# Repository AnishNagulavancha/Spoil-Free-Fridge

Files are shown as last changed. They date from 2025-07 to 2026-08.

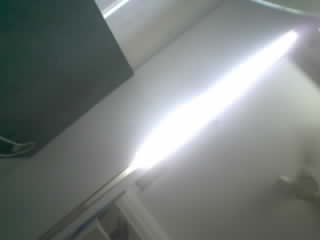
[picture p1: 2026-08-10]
firmware/main/capture_test_output/capture_test_2_20260808_180124.jpg

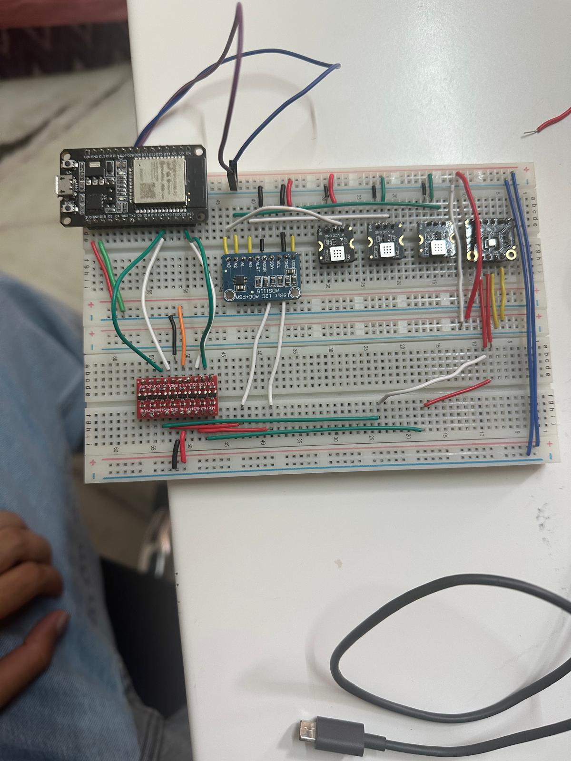
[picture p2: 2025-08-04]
Visuals and Designs/BreadBoard Prototype build.jpeg

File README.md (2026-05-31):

# Spoil-Free-Fridge
This project is a battery-powered, IOT system designed to detect early signs of food spoilage in refrigerators by monitoring the release of specific gases and image classification. It uses dedicated gas sensors (specifically, hydrogen sulfide, ammonia, and methane) along with an environmental sensor (BME688) and and ESP32-S3 Sense to track changes in air composition over time.

The collected data is transmitted to a PC over Wi-Fi using an ESP32-S3 microcontroller. A machine learning model, trained on labeled gas profiles of different food states, will follow a multi-classification approach by being able to recongize food type, food item, and finally the freshness level as fresh, spoiling, or spoiled. Another model will use a public dataset of images of fresh vs rotten for visual detection.

The system is optimized for low power consumption, designed to operate off a LiPo, and intended for eventual deployment inside consumer refrigerators as a compact, standalone freshness detection unit.

Currently, a custom PCB is being designed and a 3D CAD model will be designed for the outer casing of the PCB. Initially, we will see if the prototype is accurate enough to work in normal conditions before moving to a fridge

The inspiration of this project came out my own laziness of postponing when I would cook my own meals leading to food spoiling in the fridge.

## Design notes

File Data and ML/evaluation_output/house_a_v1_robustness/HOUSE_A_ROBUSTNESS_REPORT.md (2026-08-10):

# House A robustness analysis

## Status

HouseA_v1 remains the primary frozen result. All analyses below are robustness
checks or retrospective exploratory analyses; none changes the frozen result.

## Frozen benchmark

- Confirmations detected: 3/3
- Calibration-control events under the full calibration: 0/3
- Confirmation detection range: 1.75–3.75 h
- Confirmation AUC range: 206.48–313.48
- Calibration-control AUC range: 0.47–10.92

The controls above participated in calibration; their zero-event count is a
calibration diagnostic, not an independent false-positive estimate.

## Full leave-one-control-out result

- Held-out controls with events: 1/3
- Confirmation detections across folds: 3–3 of 3
- Minimum fold-level absolute AUC margin: 118.83
- Detection times across calibrations: 1.25–4.25 h

## Parameter sensitivity

- 23/23 configurations retained all three confirmation events.
- 0/23 produced zero leave-one-control-out control events.
- 23/23 retained a positive minimum-chicken minus maximum-control AUC margin.
- 0/23 (0.0%) met all three criteria simultaneously.

These are grid-robustness proportions, not probabilities that the detector is
biologically correct.

## Ablation

- Event rules retaining 3/3 confirmations and 0/3 controls: h2s_and_bme
- Index variants with positive minimum-confirmation minus maximum-control AUC margin: 6/6

## Control bootstrap stress test

For the eight-hour window, conditional moving-block bootstrap false-session
rates ranged from 0.00% to
16.35% across 15–90 minute blocks. The
intervals in the CSV quantify Monte Carlo error only; three observed controls
cannot characterize between-session or between-house uncertainty.

One of 12 shifted-baseline control stress tests produced an event.
It was house_A_pcb_A_S005_Anish_control_empty_20260724_125849
with a 120-minute shift. This shows that the cumulative event can be
sensitive to baseline placement even when the displayed index remains small.

## Environmental sensitivity

Environment-adjusted detection pairs (original → adjusted, hours):
3.75 → 5.92; 1.75 → 5.50; 2.00 → 8.75.

Every environmental result is exploratory because the chicken sessions extend
beyond the control humidity/temperature training domain. A changed detection
time demonstrates sensitivity to the adjustment; it does not identify a true
biological onset.

The prespecified delta-RH plus delta-temperature model had mean held-out RMSE
0.0800, versus 0.0705 for the simple time-only regression.
It therefore did not improve aggregate control generalization and should not
replace the frozen correction.

## Alternative transition estimates

The detailed table distinguishes online CUSUM onset, a control-calibrated rapid
rise, Page–Hinkley onset, and an offline whole-trajectory mean shift. Agreement
indicates a stable statistical transition, not microbiological validation.
The offline mean-shift locations were
4.75 h, 4.75 h, 6.67 h;
their absolute shift magnitudes exceeded every leave-one-control-out control,
although their normalized SSE gains did not. Page–Hinkley onsets were
4.92 h, 4.67 h, 6.33 h.

## Session-level inference

- Perfect descriptive AUC ordering: True
- LOO-control AUC range: 0.31–54.18
- Confirmation AUC range: 206.48–313.48
- Pairwise Hodges–Lehmann location difference: 238.20 index-hours

No formal permutation p-value is reported because the available controls define
the calibration and are not untouched exchangeable validation sessions.

## Quality flags

The quality flags are deterministic diagnostics, not calibrated probabilities.
Flag counts across confirmations: 3, 3, 3.

## Conclusion

The magnitude separation is robust: every parameter and index ablation retained
a positive chicken-versus-control AUC margin. The exact Boolean event and its
onset are less robust because one cross-fitted control fires and onset varies
with calibration and transition method. The appropriate claim remains that
chicken exposure produced a repeatable, sustained, control-adjusted multichannel
headspace response in the House A apparatus. These analyses cannot establish
microbial spoilage, food safety, remaining useful life, or universal household
performance.

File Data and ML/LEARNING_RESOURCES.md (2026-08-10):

# Learning guide for the control-calibrated prototype

This guide explains what the active files do, the theory behind them, and a
practical order for learning the implementation. The pipeline estimates
**deterioration-associated sensor and image change**. It does not measure food
safety or microbiological spoilage unless it is validated against laboratory
ground truth.

## 1. Read the project in this order

1. `Datalog_pcb.py` — serial acquisition, warmup/prompt phases, metadata,
   images, and session roles.
2. `analyze_session.py` — parsing, cleaning, timestamp indexing, one-minute
   aggregation, baselines, deltas, rolling slopes, volatility, and biological
   age.
3. `configs/house_a_v1.json`, `configs/house_a_v2_candidate.json`, and
   `experiment_config.py` — versioned frozen choices and validation.
4. `model_data.py` — loading and resampling complete sessions without treating
   adjacent rows as independent experiments.
5. `unsupervised_models.py` — control drift correction, leave-one-control-out
   scale estimation, CUSUM calibration, PCA, Isolation Forest, and the change
   index.
6. `run_models.py` — command-line orchestration and safeguards separating
   controls, pilot data, and confirmation data.
7. `aggregate_site_results.py` — session-level cross-house summaries without
   pooling autocorrelated raw sensor rows.
8. `image_data.py` and `image_features.py` — image timestamps, ROIs, color,
   histogram, texture, edge, blur, and baseline-relative features.
9. `camera_models.py` and `run_camera_models.py` — camera baseline model,
   condensation gate, anomaly persistence, and reliability by hour.

Before reading the project, work through the
[Python tutorial](https://docs.python.org/3/tutorial/index.html),
[NumPy quickstart](https://numpy.org/doc/stable/user/quickstart.html), and
[pandas time-series guide](https://pandas.pydata.org/docs/user_guide/timeseries.html).
The [pySerial introduction](https://pyserial.readthedocs.io/en/stable/shortintro.html)
matches the serial-port concepts used by the logger.

## 2. Cleaning, resampling, and feature engineering

The raw samples are autocorrelated and much faster than the biological changes
of interest. Median aggregation reduces isolated spikes without pretending that
every two-second sample is an independent experiment. Learn pandas
[`resample`](https://pandas.pydata.org/docs/user_guide/timeseries.html#resampling)
and [`rolling`](https://pandas.pydata.org/pandas-docs/stable/reference/api/pandas.DataFrame.rolling.html),
then review NIST's
[least-squares regression](https://www.itl.nist.gov/div898/handbook/pmd/section1/pmd141.htm).
The rolling slope is simply the fitted coefficient of time over a moving
window; acceleration is a slope of those slopes.

The biological-age feature uses the explicit engineering assumption

```text
Q10 factor = 2 ** ((temperature_C - 4) / 10)
biological hours += Q10 factor * elapsed_clock_hours
```

Q10 describes how a deterioration rate changes for a 10 degrees C temperature
change. It is a model assumption, not a sensor measurement and not proof of
shelf life. A useful food-cold-chain introduction is the
[FAO discussion of Q10](https://openknowledge.fao.org/3/i8017en/I8017EN.pdf).

Practice:

1. Create a noisy synthetic signal with a few spikes and compare one-minute
   means with medians.
2. Implement a rolling five-point slope by hand, then compare it with the
   project output.
3. Calculate biological age for constant 4, 14, and 24 degrees C data and
   explain why the factors are 1, 2, and 4.

## 3. Controls, robust scale, and drift correction

An empty control measures environmental and instrument behavior when chicken is
absent. The code pools controls to estimate smooth expected drift. It then uses
leave-one-control-out residuals: fit the correction without one control, apply
it to that held-out control, and measure the remaining null variation. This
tests the complete correction process instead of only the baseline noise.

The residual scale uses median absolute deviation (MAD), a robust alternative
to standard deviation. Read the
[SciPy MAD definition](https://docs.scipy.org/doc/scipy/reference/generated/scipy.stats.median_abs_deviation.html)
and NIST's
[LOESS overview](https://www.itl.nist.gov/div898/handbook/pmd/section1/pmd144.htm)
for the reasoning behind robust scale and smooth drift estimation. The project
uses its own deterministic smoothing implementation, so focus on the ideas
rather than expecting identical library calls.

The block bootstrap resamples consecutive blocks instead of individual rows so
short-range time dependence is retained. The original reference is Kunsch,
[The Jackknife and the Bootstrap for General Stationary Observations](https://doi.org/10.1214/aos/1176347265).

Practice:

1. Implement `MAD = 1.4826 * median(abs(x - median(x)))` and test it after
   adding one extreme outlier.
2. Hold out each of three synthetic controls, fit drift on the other two, and
   plot the held-out residuals.
3. Compare an ordinary row bootstrap with a block bootstrap on a slowly varying
   signal.

## 4. CUSUM and the primary event rule

CUSUM accumulates small deviations that persist in one direction. For a
standardized response `z`, the one-sided update is conceptually

```text
C_t = max(0, C_(t-1) + z_t - k)
signal when C_t > h
```

`k` ignores small movement and `h` controls how much accumulated evidence is
required. Study NIST's
[CUSUM control-chart explanation](https://www.itl.nist.gov/div898/handbook/pmc/section3/pmc323.htm)
and [average run length](https://www.itl.nist.gov/div898/handbook/pmc/section3/pmc3131.htm).
This project calibrates CUSUM behavior using empty controls and freezes the rule
before prospective scoring. HouseA_v1 uses `(NH3 or H2S) AND BME688`.
HouseA_v2 uses `H2S AND BME688`, selected from the excluded pilot and
cross-fitted controls. CH4 remains supporting evidence. This is evidence
agreement, not proof that the channels are independent.

Practice: implement the recurrence above in ten lines, feed it zero-mean noise,
then add a small sustained shift. Compare how detection changes for different
`k` and `h` values.

## 5. PCA, Isolation Forest, and the change index

PCA rotates correlated standardized channels into orthogonal directions that
capture decreasing amounts of variance. It is a visualization and compression
tool, not a spoilage detector. Read the scikit-learn
[PCA documentation](https://scikit-learn.org/stable/modules/generated/sklearn.decomposition.PCA.html).
Always inspect component loadings and compare control and chicken trajectories;
otherwise PC1 may simply describe drift or elapsed time.

Isolation Forest isolates unusual observations through random feature splits;
points requiring fewer splits are more anomalous. Start with the
[original paper](https://doi.org/10.1109/ICDM.2008.17), then read the
[scikit-learn implementation](https://scikit-learn.org/stable/modules/generated/sklearn.ensemble.IsolationForest.html).
The model is fitted to corrected control-null data, so its question is
"unusual relative to empty controls?" rather than "spoiled?".

The 0-100 change index is a transparent engineered metric: each directed,
control-corrected z-score is clipped to 0-1 using the frozen `full_scale_z`,
then the channels are combined with the weight set in the selected versioned
configuration. Those weights are a documented protein-food
heuristic, not learned coefficients. They affect the index but not the primary
CUSUM agreement event. AUC is integrated only over the fixed 0-8 hour window
and is invalidated when coverage rules fail. This keeps it comparable across
complete sessions, but the index remains a prototype effect-size scale rather
than a probability or percentage spoiled.

Practice:

1. Fit PCA to two correlated synthetic sensors and reproduce the transformed
   coordinates from the component matrix.
2. Fit Isolation Forest to a cloud of normal points plus five distant points;
   inspect scores rather than only binary labels.
3. Recalculate one row of the project change index by hand from its four
   corrected z-scores and the JSON weights.

## 6. Camera theory

The camera pipeline uses fixed regions of interest and interpretable features,
not a CNN. With only a few sessions, a CNN would mostly learn lighting,
container position, and condensation. Begin with the
[Pillow tutorial](https://pillow.readthedocs.io/en/stable/handbook/tutorial.html)
for loading, cropping, and transforming images. For edges and the blur gate,
read OpenCV's explanation of
[image gradients and the Laplacian](https://docs.opencv.org/master/d5/d0f/tutorial_py_gradients.html).

Laplacian variance falls when sharp edges disappear. The code requires both the
chicken ROI and a stationary background ROI to become blurry before treating a
frame as likely fogged. Rejected frames cannot build a persistent anomaly, and
reliability is reported over time so late-session condensation is visible.

Practice:

1. Crop the same ROI from a sharp image and a blurred copy; calculate
   Laplacian variance for both.
2. Change image brightness without changing the object and observe which color
   and histogram features move.
3. Cover only the chicken ROI, then blur the whole image, and verify why the
   background ROI distinguishes occlusion/change from global fogging.

## 7. Experimental validity and ground truth

The most important modeling rule is to keep confirmation sessions and sites
untouched while choosing directions, thresholds, weights, and scales. Read scikit-learn's
[data-leakage guidance](https://scikit-learn.org/stable/common_pitfalls.html#data-leakage)
and the OSF
[registration guide](https://help.osf.io/article/330-welcome-to-registrations)
to understand why the pilot is excluded and the configuration is frozen.

The exact sensor directions and limitations must come from the manufacturers'
datasheets and independent response checks. For the BME688, use Bosch's
[product documentation and datasheet](https://www.bosch-sensortec.com/en/products/environmental-sensors/gas-sensors/bme688/).
Do not improvise concentrated toxic-gas sources.

Visible observations are useful supporting annotations, but defensible
spoilage ground truth needs independent measurements. The FDA's
[Bacteriological Analytical Manual](https://www.fda.gov/food/laboratory-methods-food/bacteriological-analytical-manual-bam)
and [Aerobic Plate Count chapter](https://www.fda.gov/food/laboratory-methods-food/bam-chapter-3-aerobic-plate-count)
show what a microbiological reference method looks like. Until those data
exist, report detection latency, control-adjusted index, fixed-window AUC,
sensor agreement, camera reliability, and repeatability across independent
sessions—not accuracy, sensitivity, specificity, freshness probability, or
remaining shelf life.

## 8. Cross-house generalization

The portable design separates local calibration from global logic. Each
site/device/container estimates its own baseline, drift, and residual noise;
the sensor directions, CUSUM rule, persistence, index weights, and scale remain
globally frozen. Never average raw voltages across houses. Compare standardized
session-level metrics instead.

If two houses influence model choices, both are development sites. Test the
frozen procedure at an untouched third house to evaluate external transfer.
Later, use leave-one-house-out validation: develop on every site except one and
evaluate the complete calibration-and-detection procedure at the held-out site.

## 9. Accelerated two-week study plan

- Days 1–2: Python, NumPy, pandas, and serial logging; trace one row from serial
  input to `sensor_log.csv`.
- Days 3–4: resampling, baselines, deltas, rolling statistics, MAD, and Q10;
  reproduce one feature column in a scratch script.
- Days 5–6: implement CUSUM from scratch and understand the primary agreement
  rule.
- Days 7–8: PCA and Isolation Forest on synthetic data, then empty controls.
- Days 9–10: image ROIs, color features, Laplacian variance, condensation, and
  anomaly persistence.
- Days 11–12: run a short practice session through every command and inspect
  each output.
- Days 13–14: explain the design, assumptions, failure modes, and claims
  without relying on the code.

This is roughly 25–35 focused hours. You are not expected to reproduce every
file from memory; you should be able to explain the major decisions, follow one
reading through the pipeline, run it, interpret it, and make small documented
changes.

For every algorithm, use the same loop: derive the smallest formula, implement
it on synthetic data, plot failure cases, then read the corresponding project
function. That will teach you more than trying to understand the entire
pipeline in one pass.

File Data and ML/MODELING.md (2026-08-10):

# Sensor and camera modeling workflow

This prototype detects control-adjusted headspace change. It does not measure
microbial counts, determine food safety, report a percentage spoiled, or provide
a validated remaining-useful-life estimate.

## Active analysis versions

- `configs/house_a_v1.json` reproduces the completed House A analysis. Its
  primary event is `(NH3 OR H2S) AND BME`.
- `configs/house_a_v2_candidate.json` is frozen for the next prospective test.
  Its primary event is `H2S AND BME`, selected from the excluded pilot and
  cross-fitted controls. It is not yet prospectively validated.

The acquisition metadata retains the historical protocol identifier
`prototype_1_control_calibrated_4h_v2` for compatibility. The active analysis
window is eight hours.

## Acquisition and feature generation

`Datalog_pcb.py` records sensors, images, metadata, a 30-minute empty-chamber
warmup, and the post-prompt session. A prospective session used for the frozen
analysis must contain at least eight post-prompt hours.

After acquisition, create the one-minute features:

```powershell
python analyze_session.py "C:\path\to\session"
```

The default is the v2 candidate configuration. Use `--config` explicitly when
reproducing v1.

## Local control calibration

Each site/device/container requires its own controls. Do not pool raw voltages
across houses.

```powershell
python run_models.py `
  --controls "C:\data\C1" "C:\data\C2" "C:\data\C3" `
  --config configs\house_a_v2_candidate.json `
  --output-dir "house_A_v2_model"
```

Calibration estimates smoothed drift, leave-one-control-out MAD scales, the
control-null CUSUM behavior, PCA, Isolation Forest, and the environmental range
represented by the controls.

## Prospective scoring

Do not change the v2 candidate before scoring the next untouched session:

```powershell
python run_models.py `
  --calibration "evaluation_output\house_a_v2_candidate\control_calibration_candidate.joblib" `
  --targets "C:\data\new_session" `
  --config configs\house_a_v2_candidate.json `
  --output-dir "prospective_v2_result"
```

Interpret the outputs as follows:

- The 0–100 Change Index is an engineered response magnitude, not a spoilage
  percentage.
- The Boolean event is sustained multichannel departure from the control model,
  not the moment food becomes unsafe.
- `environment_domain_warning=true` means the session left the temperature or
  humidity range represented by the controls; the event remains visible but
  requires caution.
- AUC is always evaluated over the fixed 0–8-hour window.

## Reproduction and robustness

Rebuild the completed v1 robustness outputs with:

```powershell
python house_a_robustness.py
```

Rebuild the frozen v2 candidate selection and diagnostics with:

```powershell
python run_house_a_v2_candidate.py
```

Canonical generated results are kept in:

- `evaluation_output/full_stack_4runs_20260806` — processed House A sessions
  and the original v1 calibration;
- `evaluation_output/house_a_v1_robustness` — v1 robustness findings;
- `evaluation_output/house_a_v2_candidate` — frozen v2 candidate artifact and
  retrospective diagnostics.

## Camera analysis

Camera analysis is optional and separate from the present sensor conclusion:

```powershell
python run_camera_models.py "C:\path\to\session" `
  --roi .1,.2,.9,.9 `
  --background-roi 0,0,1,.15
```

Fogged or unreliable frames are flagged and cannot establish food safety.

## Cross-site results

Score every site with its own local calibration but the same frozen global
configuration. Combine only confirmation-level summaries:

```powershell
python aggregate_site_results.py `
  "house_A_result\sensor_summary.json" `
  "house_B_result\sensor_summary.json" `
  --output cross_site_summary.json
```

Generalization requires prospective sessions from additional devices, houses,
environmental ranges, and ultimately independent biological ground truth.

## Installation and tests

```powershell
python -m pip install -r requirements.txt
python -m pytest -q
```

See `LEARNING_RESOURCES.md` for theory and implementation references.

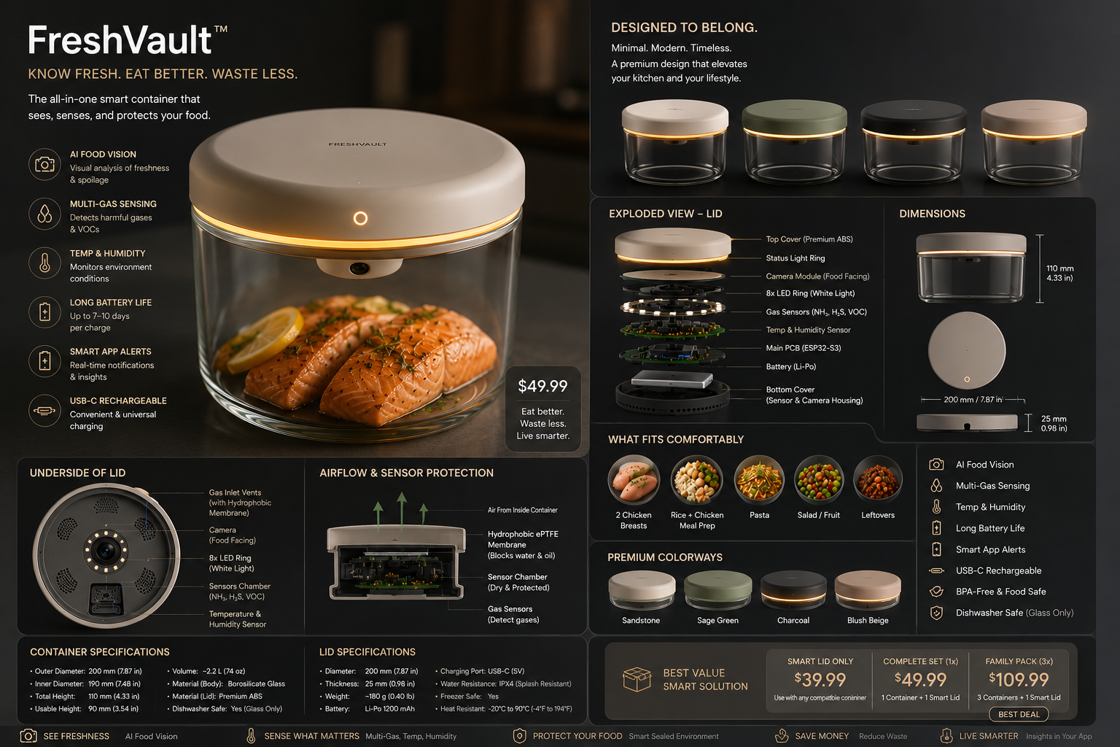
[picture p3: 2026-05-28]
Visuals and Designs/Prototype Visual #1.png

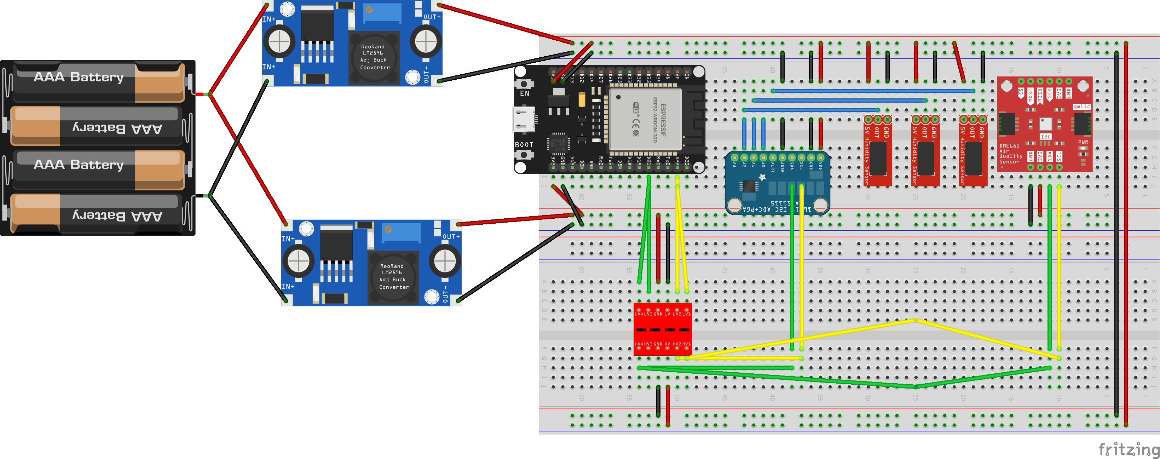
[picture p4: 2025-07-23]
Visuals and Designs/Fritzing prototype design.jpg

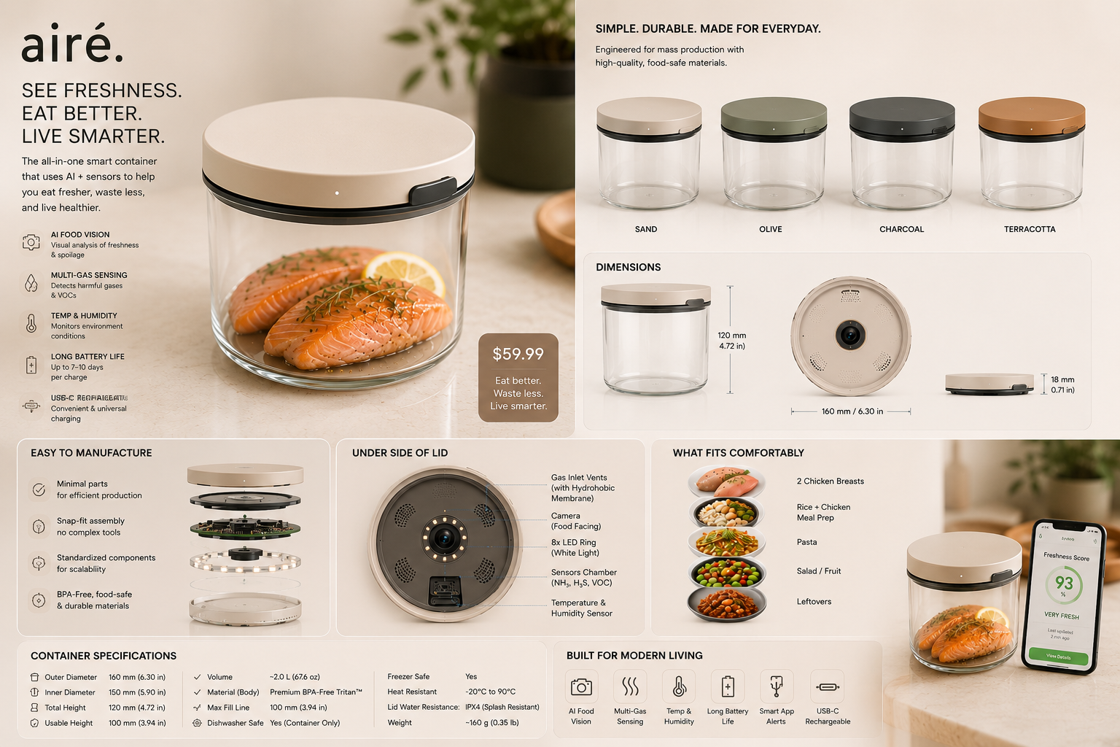
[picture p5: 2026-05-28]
Visuals and Designs/Prototype Visual #2.png

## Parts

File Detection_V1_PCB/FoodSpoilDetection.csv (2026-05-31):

Reference | Qty | Value | DNP | Exclude from BOM | Exclude from Board | Footprint | Datasheet
3v1,A1,A2,GND1,SCL1,SDA1 | 6 | TestPoint |  |  |  | TestPoint:TestPoint_Loop_D1.80mm_Drill1.0mm_Beaded | ~
D1,D2,D3,D4,D5,D6,D7,D8 | 8 | LED |  |  |  | LED_SMD:LED_0603_1608Metric | ~
FID1,FID2,FID3 | 3 | Fiducial |  | Excluded from BOM |  | Fiducial:Fiducial_1.5mm_Mask3mm | ~
H1,H2,H3,H4 | 4 | MountingHole_Pad |  | Excluded from BOM |  | MountingHole:MountingHole_3.2mm_M3_Pad_TopBottom | ~
J1,J4,J6 | 3 | Conn_01x03_Socket |  |  |  | Connector_PinSocket_2.54mm:PinSocket_1x03_P2.54mm_Vertical | ~
J2 | 1 | Conn_01x04_Socket |  |  |  | Connector_PinSocket_2.54mm:PinSocket_1x04_P2.54mm_Vertical | ~
J3 | 1 | Conn_01x06_Socket |  |  |  | Connector_PinSocket_2.54mm:PinSocket_1x06_P2.54mm_Vertical | ~
J5 | 1 | Conn_01x10_Socket |  |  |  | Connector_PinSocket_2.54mm:PinSocket_1x10_P2.54mm_Vertical | ~
Q1,Q3 | 2 | AO3401A |  |  |  | Package_TO_SOT_SMD:SOT-23 | http://www.aosmd.com/pdfs/datasheet/AO3401A.pdf
Q2 | 1 | AO3400A |  |  |  | Package_TO_SOT_SMD:SOT-23 | http://www.aosmd.com/pdfs/datasheet/AO3400A.pdf
R1,R2,R3,R4,R5,R6,R8,R10 | 8 | 1K |  |  |  | Resistor_SMD:R_0603_1608Metric_Pad0.98x0.95mm_HandSolder | ~
R7,R9,R11 | 3 | 100K |  |  |  | Resistor_SMD:R_0603_1608Metric_Pad0.98x0.95mm_HandSolder | ~
SW1 | 1 | SW_DIP_x01 |  |  |  | Button_Switch_SMD:SW_SPDT_PCM12 | ~
TP1 | 1 | A3 |  |  |  | TestPoint:TestPoint_Loop_D1.80mm_Drill1.0mm_Beaded | ~
U1 | 1 | XIAO-ESP32-S3-DIP |  |  |  | esp32s3:XIAO-ESP32-S3-DIP

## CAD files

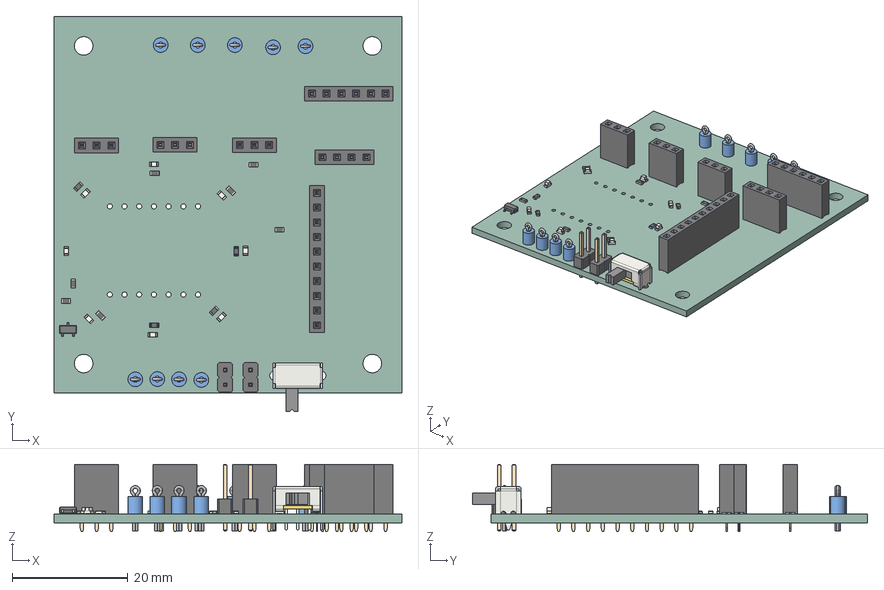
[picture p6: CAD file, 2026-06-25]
Detection_V1_PCB/FoodSpoilDetection.step
60.0 x 68.2 x 11.6 mm
R_0603_1608Metric x 11
LED_0603_1608Metric x 8
TestPoint_Loop_D1.80mm_Drill1.0mm_Beaded x 9
PinSocket_1x06_P2.54mm_Vertical
PinSocket_1x03_P2.54mm_Vertical x 3
PinSocket_1x10_P2.54mm_Vertical
PinHeader_1x02_P2.54mm_Vertical x 2
PinSocket_1x04_P2.54mm_Vertical
SOT-23
SW_Slide_SPDT_Angled_CK_OS102011MA1Q
FoodSpoilDetection_PCB

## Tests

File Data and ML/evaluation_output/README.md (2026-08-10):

# Canonical evaluation artifacts

Only the current House A provenance chain is retained here:

- `full_stack_4runs_20260806/` contains the final aggregate reports, plot, and
  compact result summaries for three controls, one excluded pilot, and three
  confirmations.
- `house_a_v1_robustness/` contains the completed robustness report and compact
  audit summaries for v1.
- `house_a_v2_candidate/` contains the frozen v2 configuration, final report,
  development-only rule selection, and compact session summaries.

Staged features, fitted joblib files, detailed per-bin metrics, and sensitivity
tables are regenerated by the analysis scripts and are intentionally ignored.
Raw acquisition folders remain outside `evaluation_output` and must not be
treated as generated disposable files.

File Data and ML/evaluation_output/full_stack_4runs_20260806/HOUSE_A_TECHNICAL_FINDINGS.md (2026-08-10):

# House A technical findings

## Experimental scope

The final House A dataset contains three local empty-container controls and
four chicken sessions acquired with the same PCB design, physical device, and
chamber:

- S005, S006, S007: empty controls;
- S010: excluded development pilot;
- Chicken 2: confirmation 1, with the acquisition-time role corrected from
  `pilot` to `confirmation` while retaining the original value for audit;
- Chicken 3: confirmation 2; and
- Chicken 4: confirmation 3, started from a longer-refrigerated condition.

All primary comparisons use the first eight hours after the insertion/control
prompt. Chicken recordings longer than eight hours are truncated only for the
matched AUC and fixed-time comparisons. Camera results are excluded.

## Signal processing

Warmup rows are discarded. Timestamp and sensor fields are converted to
numeric values; nonfinite values, physically invalid temperature/humidity,
nonpositive BME resistance, and gas voltages outside 0–5.5 V are rejected.
Only exactly duplicated measurement records are removed. Buffered serial
measurements sharing a rounded host timestamp are retained when their sensor
values differ.

Valid raw data are reduced to one-minute medians for feature construction and
then five-minute medians for control calibration and scoring. The first 30
minutes after the prompt form each session's food/handling baseline.

For gas channel `j`, the baseline-relative feature is

```text
D_j(t) = V_j(t) / mean_baseline(V_j) - 1
```

For BME resistance, rising VOC response is represented with an inverted
log-ratio:

```text
D_BME(t) = ln(mean_baseline(R_BME) / R_BME(t))
```

The feature stage also computes least-squares rolling slopes over 5, 15, and
30 minutes, slope-of-slope acceleration, rolling standard deviation, and Q10
biological age:

```text
Q10(t) = 2^((T(t) - 4) / 10)
biological_age = integral Q10(t) dt
```

Those additional trend and Q10 features are retained for diagnostics. They do
not currently enter the frozen primary event or displayed Change Index.

## Local control calibration

The three empty controls are pooled to estimate a smoothed expected drift curve
for each baseline-relative channel. Leave-one-control-out residuals are
generated by fitting drift on two controls and applying it to the third. Robust
MAD scales from those residuals are:

| Channel | LOO robust scale |
|---|---:|
| NH3 | 0.029649 |
| H2S | 0.065507 |
| CH4 | 0.078839 |
| BME | 0.055924 |

For sensor `j`, the control-standardized response is

```text
z_j(t) = direction_j * (D_j(t) - control_drift_j(t)) / scale_j
```

All frozen direction multipliers are `+1`. Negative responses are clipped to
zero for the displayed index; they do not cancel positive channels.

Each channel is mapped to 0–1 by

```text
G_j(t) = clip(z_j(t) / 40, 0, 1)
```

The 0–100 Deterioration-Associated Change Index is

```text
Index(t) = 100 * [0.30 G_NH3 + 0.35 G_H2S + 0.10 G_CH4 + 0.25 G_BME]
```

The weights are a frozen protein-food engineering heuristic, not coefficients
estimated from the confirmation data. A channel value reaches its display
ceiling when its corrected response reaches 40 control residual scales. This
is numerical clipping, not necessarily raw sensor saturation. Index 100 does
not mean 100% spoiled.

## Primary event definition

For each standardized channel, a one-sided CUSUM is calculated on five-minute
bins:

```text
C_j(t) = max(0, C_j(t-1) + z_j(t) - k)
k = 0.5
h = 30
```

A channel becomes active after `C_j > 30` for three consecutive bins (15
minutes). The frozen primary event is

```text
(NH3 active OR H2S active) AND BME active
```

CH4 is supporting evidence and is not required. The threshold `h=30` was
selected using empty controls only. A 2,000-session moving-block bootstrap of
the control-null residuals estimated a 1.25% false-session probability for the
complete eight-hour primary rule. None of the three observed controls produced
a primary event.

CUSUM detection time is the earliest persistent departure from expected empty
behavior. It is not the biological onset of spoilage and need not coincide with
the steepest part of the displayed index curve.

## Per-session results

| Metric | Excluded pilot | Confirmation 1 | Confirmation 2 | Confirmation 3 |
|---|---:|---:|---:|---:|
| CUSUM primary detection | 4.08 h | 3.75 h | 1.75 h | 2.00 h |
| Index at 1 h | 3.47 | 1.00 | 3.44 | 9.38 |
| Index at 2 h | 3.80 | 3.92 | 16.09 | 11.98 |
| Index at 3 h | 4.53 | 2.35 | 13.34 | 12.96 |
| Index at 4 h | 19.12 | 17.17 | 21.26 | 13.61 |
| Index at 6 h | 80.31 | 53.30 | 76.73 | 27.96 |
| Index at 8 h | 79.31 | 89.32 | 80.04 | 87.28 |
| AUC, 0–8 h | 291.45 | 264.13 | 313.48 | 206.48 |
| Maximum over recorded session | 91.40 | 90.95 | 89.99 | 91.71 |

All four chicken sessions satisfy the primary event rule. The three local
controls have no primary events, maximum indices of 0.39–4.56, and eight-hour
AUC values of 0.47–10.92. Chicken maxima are 89.99–91.71 and chicken AUC values
are 206.48–313.48. Thus there is no observed overlap between control and
chicken sessions for maximum index or eight-hour AUC. The minimum chicken AUC
is approximately 18.9 times the maximum control AUC.

This apparent 4/4 chicken detection and 0/3 control detection must not be
reported as 100% diagnostic accuracy: the sample is very small, all data come
from one local setup, the pilot is development data, and no independent
biological labels are available.

## Repeatability statistics

Across the three confirmation sessions only:

- detection latency: mean 2.50 h, SD 1.09 h, range 1.75–3.75 h;
- index at hour 4: mean 17.35, SD 3.83;
- index at hour 6: mean 52.67, SD 24.39;
- index at hour 8: mean 85.54, SD 4.88; and
- AUC 0–8 h: mean 261.36 index-hours, SD 53.55.

Across all four chicken trajectories descriptively:

- detection latency: 2.90 ± 1.19 h;
- index at hour 4: 17.79 ± 3.25;
- index at hour 6: 59.58 ± 24.24;
- index at hour 8: 83.99 ± 5.06; and
- AUC 0–8 h: 268.89 ± 46.24 index-hours.

The large hour-6 variance and much smaller hour-8 variance show that session
timing varies substantially but the eventual eight-hour response is more
repeatable.

## Rapid-response phase versus CUSUM onset

Three trajectories begin their large rise around 3.5–4 hours and remain above
index 50 for three consecutive bins by 4.92–5.00 hours. The longer-refrigerated
confirmation remains above 50 only at 6.83 hours. This descriptive threshold
was calculated after observing the trajectories and is not a frozen biological
decision boundary.

Accordingly, the data support two different time concepts:

1. **CUSUM response onset:** earliest sustained multi-channel departure from
   empty-control behavior, 1.75–4.08 hours.
2. **Large-response phase:** strong increase in corrected response magnitude,
   near five hours for the first three trajectories and later for the
   refrigerated sample.

Neither quantity is a proven time at which the food "became spoiled."
Deterioration is continuous, and a biological transition requires independent
ground truth.

## Unsupervised diagnostics

PCA and Isolation Forest are fitted only to locally standardized control-null
data. During hours 4–8, every five-minute bin in every chicken session is
classified anomalous by Isolation Forest. Whole-window chicken anomaly
fractions are 88.7–99.0%.

The median absolute PC1 coordinate for control-null data is approximately 0.69.
During chicken hours 4–8, median absolute PC1 is 11.60–32.29. This demonstrates
large multivariate separation from the control state. PCA direction and
Isolation Forest anomaly status do not provide a probability of spoilage.

## Environmental and independence limitations

Within chicken sessions, corrected gas/BME trajectories are often highly
correlated. This can reflect shared biological headspace response, common
humidity/temperature sensitivity, or sensor cross-sensitivity. The four
channels therefore cannot be counted as four independent biological lines of
evidence.

The refrigerated confirmation illustrates this limitation: its early BME
response has first-difference correlation of approximately 0.49 with humidity
and 0.46 with temperature. Its primary CUSUM event occurs at 2.00 hours, while
the large NH3/H2S/BME rise occurs much later. Temperature/humidity compensation
or an explicit confidence penalty remains necessary for deployment.

BME temperature is PCB/chamber-adjacent, approximately 30–31 C, rather than
food core temperature. Q10 biological age derived from it is supporting
metadata and should not be treated as food-age ground truth.

## Technical conclusion

The frozen House A algorithm reproducibly distinguishes chicken sessions from
local empty-container behavior. All three independent confirmations and the
excluded pilot exhibit a sustained protein-gas-plus-BME event, large
control-adjusted AUC, and strong PCA/Isolation-Forest separation. The most
repeatable descriptive endpoint is the high eight-hour Change Index, not a
fixed four-hour biological transition.

The evidence supports the statement:

> In this PCB/chamber/household setup, chicken exposure produced a repeatable,
> sustained, control-adjusted multi-sensor headspace response substantially
> exceeding empty-container drift.

The evidence does not establish microbiological spoilage, pathogen presence,
edibility, a safety threshold, percentage spoiled, remaining useful life, or
generalization to another household. Those claims require independent ground
truth and external validation with a frozen model.

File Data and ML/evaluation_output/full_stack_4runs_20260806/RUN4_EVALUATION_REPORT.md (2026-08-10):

# Chicken 4 / Confirmation Run 3 evaluation

## Scope and data quality

- Completed session: `house_A_pcb_A_S012_Anish_chicken4_confirmation_chicken_20260805_225737`
- The similarly named `...225726` folder is an initialization-only folder with
  no sensor log and was excluded.
- Frozen analysis: 0–8 hours, five-minute medians, CUSUM `k=0.5`, `h=30`,
  `full_scale_z=40`, and the existing sensor weights.
- The three empty controls were reprocessed and recalibrated consistently; no
  parameter was selected using Run 4.

The logger produced 22,512 rows. Of these, 899 warmup rows were removed, zero
post-warmup rows contained corrupt sensor values, seven exact duplicate records
were removed, and 21,606 valid post-warmup measurements were retained.

The first cleaning pass appeared to reject 3,449 rows because serial backlog
can assign the same rounded host timestamp and elapsed value to multiple
different buffered sensor readings. Deduplication was corrected to remove only
exactly duplicated measurement records. All controls and chicken sessions were
then reprocessed. This changed earlier numerical scores only slightly and did
not change any detection decision.

Run 4's baseline was more variable than the earlier chicken baselines. The
baseline coefficients of variation were 2.36% for NH3, 5.67% for H2S, 3.05%
for CH4, and 8.77% for BME resistance. This reduces confidence in interpreting
the early-session timing precisely.

## Run 4 result

- Frozen primary event: detected at 2.00 hours
- Event persistence: continuously active from 2.00 through 8.00 hours
- Index at 1 hour: 9.38
- Index at 2 hours: 11.98
- Index at 3 hours: 12.96
- Index at 4 hours: 13.61
- Index at 6 hours: 27.96
- Index at 8 hours: 87.28
- AUC, 0–8 hours: 206.48 index-hours
- Maximum over the complete recorded session: 91.71

Channel CUSUM activation occurred at 1.00 hour for BME, 2.00 hours for H2S,
2.33 hours for NH3, and 3.33 hours for CH4. At hour 8 the channel indices were
NH3 100, H2S 100, CH4 9.10, and BME 85.47.

BME first-difference response has moderate correlation with humidity (0.49)
and temperature (0.46), so the early BME contribution is not cleanly
independent of chamber warming and moisture. The later hour-8 state includes
strong NH3 and H2S contributions as well as BME.

Isolation Forest marks 99.0% of Run 4's eight-hour bins anomalous relative to
the control-null state, and every bin from hours 4–8 is anomalous. This is
supporting separation evidence rather than a probability of spoilage.

## Comparison with earlier chicken runs

| Metric | Excluded pilot | Confirmation 1 | Confirmation 2 | Confirmation 3 |
|---|---:|---:|---:|---:|
| CUSUM detection | 4.08 h | 3.75 h | 1.75 h | **2.00 h** |
| Index at 4 h | 19.12 | 17.17 | 21.26 | **13.61** |
| Index at 6 h | 80.31 | 53.30 | 76.73 | **27.96** |
| Index at 8 h | 79.31 | 89.32 | 80.04 | **87.28** |
| AUC, 0–8 h | 291.45 | 264.13 | 313.48 | **206.48** |

As a descriptive secondary comparison—not a new frozen decision threshold—the
first three chicken trajectories remain above index 50 for three consecutive
bins by 4.92–5.00 hours. Run 4 does not do so until 6.83 hours. Thus its major
response is approximately 1.8–1.9 hours later, even though the cumulative
CUSUM detects its smaller early departure at 2.00 hours.

This delayed large rise is consistent with the colder/refrigerated starting
condition, but one differently stored sample cannot establish refrigeration as
the cause. Starting biological age, sensor baseline state, humidity, and
chamber carryover are competing explanations.

## Three-confirmation aggregate

All three confirmation runs detect the frozen primary event. Across them:

- detection latency mean 2.50 h, SD 1.09 h, range 1.75–3.75 h;
- mean index at hour 4: 17.35, SD 3.83;
- mean index at hour 6: 52.67, SD 24.39;
- mean index at hour 8: 85.54, SD 4.88; and
- mean 0–8-hour AUC: 261.36 index-hours, SD 53.55.

The hour-6 variation is large, showing that deterioration trajectories differ
substantially in timing. The hour-8 index is much more repeatable. These results
support a robust eventual chicken-associated headspace response in this local
setup, not an absolute spoilage percentage or food-safety threshold.

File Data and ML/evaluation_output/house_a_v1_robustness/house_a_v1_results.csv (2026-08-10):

session_id | session_role | primary_event | detection_time_h | index_1h | index_2h | index_4h | index_6h | index_8h | auc_0_8h | maximum_index
house_A_pcb_A_S005_Anish_control_empty_20260724_125849 | control | False |  | 0.12916582819261951 | 0.0400305045795972 | 1.4326393662680867 | 2.0604593802978126 | 3.337988567675046 | 9.560072274292487 | 4.564109210688325
house_A_pcb_A_S006_Anish_control_empty_20260724_222032 | control | False |  | 1.6065331763260706 | 1.3904340832260855 | 1.436282065892424 | 1.3980053703395063 | 1.266446798622402 | 10.920607984496847 | 1.971708445955814
house_A_pcb_A_S007_Anish_control_empty_20260727_212706 | control | False |  | 0.017664992352422335 | 0.28358598287943537 | 0.0 | 0.0521813299584207 | 0.0 | 0.4695361541618156 | 0.3889474483215371
house_A_pcb_A_S010_Anish_chickenreal1_pilot_chicken_20260728_193932 | pilot | True | 4.083333333333333 | 3.470262114703256 | 3.802778811983261 | 19.11674755860815 | 80.31490312715077 | 79.30906180001087 | 291.4544025861891 | 91.40463060217627
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

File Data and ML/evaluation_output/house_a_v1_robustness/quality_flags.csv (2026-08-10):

session_id | quality_flags | flag_count | environment_out_of_domain_fraction | rapid_environmental_step_at_detection
house_A_pcb_A_S012_Anish_chicken2_pilot_chicken_20260802_112823 | ["environment_outside_control_domain", "rapid_environmental_step_at_detection", "bme_leads_protein_group_by_at_least_30m"] | 3 | 1.0 | True
house_A_pcb_A_S012_Anish_chicken3_confirmation_chicken_20260804_182348 | ["environment_outside_control_domain", "rapid_environmental_step_at_detection", "baseline_cv_above_1.5x_control_max:v_CH4"] | 3 | 1.0 | True
house_A_pcb_A_S012_Anish_chicken4_confirmation_chicken_20260805_225737 | ["environment_outside_control_domain", "bme_leads_protein_group_by_at_least_30m", "baseline_cv_above_1.5x_control_max:v_NH3,v_H2S,v_CH4"] | 3 | 1.0 | False

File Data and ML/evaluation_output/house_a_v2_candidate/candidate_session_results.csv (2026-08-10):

session_id | session_role | primary_event | detection_time_h | auc_0_8h | maximum_index | environment_outside_control_domain_fraction | environment_domain_warning | index_1h | index_2h | index_4h | index_6h | index_8h
house_A_pcb_A_S005_Anish_control_empty_20260724_125849 | control | False |  | 9.560072274292487 | 4.564109210688325 | 0.0 | False | 0.12916582819261951 | 0.0400305045795972 | 1.4326393662680867 | 2.0604593802978126 | 3.337988567675046
house_A_pcb_A_S006_Anish_control_empty_20260724_222032 | control | False |  | 10.920607984496847 | 1.971708445955814 | 0.0 | False | 1.6065331763260706 | 1.3904340832260855 | 1.436282065892424 | 1.3980053703395063 | 1.266446798622402
house_A_pcb_A_S007_Anish_control_empty_20260727_212706 | control | False |  | 0.4695361541618156 | 0.3889474483215371 | 0.0 | False | 0.017664992352422335 | 0.28358598287943537 | 0.0 | 0.0521813299584207 | 0.0
house_A_pcb_A_S010_Anish_chickenreal1_pilot_chicken_20260728_193932 | pilot | True | 4.166666666666667 | 291.4544025861891 | 91.40463060217627 | 1.0 | True | 3.470262114703256 | 3.802778811983261 | 19.11674755860815 | 80.31490312715077 | 79.30906180001087
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

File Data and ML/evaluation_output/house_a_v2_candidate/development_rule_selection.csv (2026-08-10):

rule | pilot_detected | pilot_detection_h | loo_control_events | loo_control_detection_times_h | eligible_from_development_data
full | True | 4.083333333333333 | 1 | {"house_A_pcb_A_S005_Anish_control_empty_20260724_125849": 4.5, "house_A_pcb_A_S006_Anish_control_empty_20260724_222032": null, "house_A_pcb_A_S007_Anish_control_empty_20260727_212706": null} | False
nh3_and_bme | True | 4.083333333333333 | 1 | {"house_A_pcb_A_S005_Anish_control_empty_20260724_125849": 4.5, "house_A_pcb_A_S006_Anish_control_empty_20260724_222032": null, "house_A_pcb_A_S007_Anish_control_empty_20260727_212706": null} | False
h2s_and_bme | True | 4.166666666666667 | 0 | {"house_A_pcb_A_S005_Anish_control_empty_20260724_125849": null, "house_A_pcb_A_S006_Anish_control_empty_20260724_222032": null, "house_A_pcb_A_S007_Anish_control_empty_20260727_212706": null} | True
protein_only | True | 4.083333333333333 | 2 | {"house_A_pcb_A_S005_Anish_control_empty_20260724_125849": 4.5, "house_A_pcb_A_S006_Anish_control_empty_20260724_222032": 1.8333333333333333, "house_A_pcb_A_S007_Anish_control_empty_20260727_212706": null} | False
bme_only | True | 1.5 | 1 | {"house_A_pcb_A_S005_Anish_control_empty_20260724_125849": 0.16666666666666666, "house_A_pcb_A_S006_Anish_control_empty_20260724_222032": null, "house_A_pcb_A_S007_Anish_control_empty_20260727_212706": null} | False
nh3_only | True | 4.083333333333333 | 1 | {"house_A_pcb_A_S005_Anish_control_empty_20260724_125849": 4.5, "house_A_pcb_A_S006_Anish_control_empty_20260724_222032": null, "house_A_pcb_A_S007_Anish_control_empty_20260727_212706": null} | False
h2s_only | True | 4.166666666666667 | 1 | {"house_A_pcb_A_S005_Anish_control_empty_20260724_125849": null, "house_A_pcb_A_S006_Anish_control_empty_20260724_222032": 1.8333333333333333, "house_A_pcb_A_S007_Anish_control_empty_20260727_212706": null} | False
ch4_only | True | 3.0 | 1 | {"house_A_pcb_A_S005_Anish_control_empty_20260724_125849": 7.25, "house_A_pcb_A_S006_Anish_control_empty_20260724_222032": null, "house_A_pcb_A_S007_Anish_control_empty_20260727_212706": null} | False

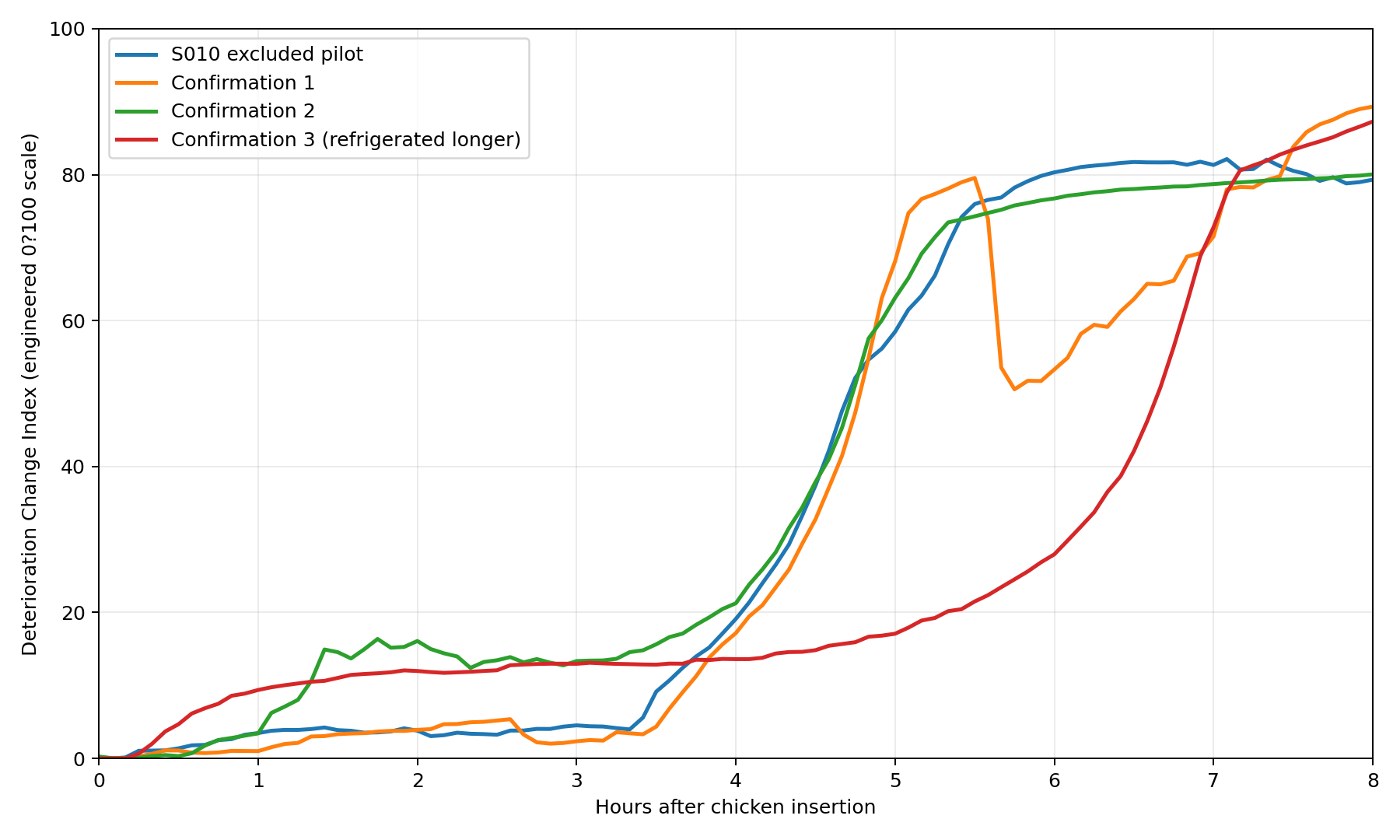
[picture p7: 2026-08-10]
Data and ML/evaluation_output/full_stack_4runs_20260806/four_run_comparison.png

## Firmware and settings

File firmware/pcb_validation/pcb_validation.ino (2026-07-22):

#include <Wire.h>
#include <WiFi.h>
#include <WebServer.h>
#include "esp_camera.h"
#include <Adafruit_ADS1X15.h>
#include "DFRobot_BME68x.h"

// =======================================================
// XIAO ESP32-S3 Sense Combined Firmware
// Sensors over Serial CSV + Camera over Wi-Fi
// LEDs turn ON only during image capture
// =======================================================

// ================= WIFI SETTINGS =================
const char* wifi_ssid = "Airtel_Sridhar";
const char* wifi_password = "air12345";

// ================= PCB PIN DEFINITIONS =================
// XIAO ESP32-S3 GPIO numbers
#define LED_PWR_PIN   1   // D0 / GPIO1, LEDs active HIGH
#define GAS_PWR_PIN   2   // D1 / GPIO2, gas sensors active LOW
#define BME_PWR_PIN   3   // D2 / GPIO3, BME688 active LOW

#define I2C_SDA       5   // D4 / GPIO5
#define I2C_SCL       6   // D5 / GPIO6

// ================= CAMERA PINS =================
#define PWDN_GPIO_NUM     -1
#define RESET_GPIO_NUM    -1
#define XCLK_GPIO_NUM     10

#define SIOD_GPIO_NUM     40
#define SIOC_GPIO_NUM     39

#define Y9_GPIO_NUM       48
#define Y8_GPIO_NUM       11
#define Y7_GPIO_NUM       12
#define Y6_GPIO_NUM       14
#define Y5_GPIO_NUM       16
#define Y4_GPIO_NUM       18
#define Y3_GPIO_NUM       17
#define Y2_GPIO_NUM       15

#define VSYNC_GPIO_NUM    38
#define HREF_GPIO_NUM     47
#define PCLK_GPIO_NUM     13

// ================= SETTINGS =================
#define SERIAL_BAUD 115200
#define I2C_FREQ    100000

// Sensor row interval
#define SENSOR_INTERVAL_MS 2000

// ================= OBJECTS =================
Adafruit_ADS1115 ads;
DFRobot_BME68x_I2C bme(0x76);
WebServer server(80);

bool adsOK = false;
bool bmeOK = false;
bool cameraOK = false;

unsigned long lastSensorRead = 0;

// ================= POWER HELPERS =================
void ledsOn()  { digitalWrite(LED_PWR_PIN, HIGH); }
void ledsOff() { digitalWrite(LED_PWR_PIN, LOW); }

void gasOn()   { digitalWrite(GAS_PWR_PIN, LOW); }
void gasOff()  { digitalWrite(GAS_PWR_PIN, HIGH); }

void bmeOn()   { digitalWrite(BME_PWR_PIN, LOW); }
void bmeOff()  { digitalWrite(BME_PWR_PIN, HIGH); }

// ================= HTML PAGE =================
const char index_html[] PROGMEM = R"rawliteral(
<!DOCTYPE html>
<html>
<head>
<title>ESP32 Food Camera</title>
<style>
body {
  font-family: Arial;
  text-align: center;
  background: #f0f0f0;
}
button {
  padding: 12px 24px;
  font-size: 18px;
  cursor: pointer;
  margin: 10px;
}
img {
  margin-top: 20px;
  border: 2px solid black;
  width: 640px;
  max-width: 95%;
}
#status {
  margin-top: 10px;
  font-weight: bold;
}
</style>
</head>

<body>
<h2>XIAO ESP32-S3 Food Camera</h2>
<button onclick="capture()">Capture Image</button>
<div id="status">Ready</div>
<br>
<img id="photo">

<script>
async function capture() {
  const status = document.getElementById("status");
  const img = document.getElementById("photo");

  status.innerText = "Capturing...";

  try {
    const response = await fetch("/capture?t=" + Date.now(), {
      cache: "no-store"
    });

    if (!response.ok) {
      status.innerText = "Capture failed: " + response.status;
      return;
    }

    const blob = await response.blob();

    if (img.src) {
      URL.revokeObjectURL(img.src);
    }

    img.src = URL.createObjectURL(blob);
    status.innerText = "Captured at " + new Date().toLocaleTimeString();

  } catch (err) {
    status.innerText = "Error: " + err;
  }
}
</script>
</body>
</html>
)rawliteral";

// ================= ADS INIT =================
bool initADS1115() {
  uint8_t addresses[] = {0x48, 0x49, 0x4A, 0x4B};

  for (int i = 0; i < 4; i++) {
    if (ads.begin(addresses[i])) {
      ads.setGain(GAIN_ONE);
      Serial.print("# ADS1115 initialized at 0x");
      Serial.println(addresses[i], HEX);
      return true;
    }
  }

  Serial.println("# ERROR: ADS1115 not found");
  return false;
}

// ================= BME INIT =================
bool initBME688() {
  for (int attempt = 1; attempt <= 5; attempt++) {
    uint8_t rslt = bme.begin();

    if (rslt == 0) {
      Serial.println("# BME688 initialized");

      bool heaterStatus = bme.setGasHeater(360, 100);
      if (heaterStatus) {
        Serial.println("# BME688 gas heater set");
      } else {
        Serial.println("# WARNING: BME688 gas heater failed");
      }

      return true;
    }

    Serial.println("# BME688 init failed, retrying...");
    delay(1000);
  }

  Serial.println("# ERROR: BME688 not initialized");
  return false;
}

// ================= CAMERA INIT =================
bool initCamera() {
  camera_config_t config;

  config.ledc_channel = LEDC_CHANNEL_0;
  config.ledc_timer   = LEDC_TIMER_0;

  config.pin_d0 = Y2_GPIO_NUM;
  config.pin_d1 = Y3_GPIO_NUM;
  config.pin_d2 = Y4_GPIO_NUM;
  config.pin_d3 = Y5_GPIO_NUM;
  config.pin_d4 = Y6_GPIO_NUM;
  config.pin_d5 = Y7_GPIO_NUM;
  config.pin_d6 = Y8_GPIO_NUM;
  config.pin_d7 = Y9_GPIO_NUM;

  config.pin_xclk = XCLK_GPIO_NUM;
  config.pin_pclk = PCLK_GPIO_NUM;
  config.pin_vsync = VSYNC_GPIO_NUM;
  config.pin_href = HREF_GPIO_NUM;

  config.pin_sccb_sda = SIOD_GPIO_NUM;
  config.pin_sccb_scl = SIOC_GPIO_NUM;

  config.pin_pwdn = PWDN_GPIO_NUM;
  config.pin_reset = RESET_GPIO_NUM;

  config.xclk_freq_hz = 20000000;
  config.pixel_format = PIXFORMAT_JPEG;

  // Use stable settings first. Increase later if stable.
  config.frame_size = FRAMESIZE_VGA;   // 640x480
  config.jpeg_quality = 10;            // lower = better quality

  config.fb_count = 1;
  config.fb_location = CAMERA_FB_IN_PSRAM;
  config.grab_mode = CAMERA_GRAB_WHEN_EMPTY;

  esp_err_t err = esp_camera_init(&config);

  if (err != ESP_OK) {
    Serial.printf("# ERROR: Camera init failed: 0x%x\n", err);
    return false;
  }

  sensor_t *s = esp_camera_sensor_get();

  s->set_brightness(s, -1);
  s->set_contrast(s, 1);
  s->set_saturation(s, 0);

  s->set_gain_ctrl(s, 1);
  s->set_exposure_ctrl(s, 1);
  s->set_whitebal(s, 1);
  s->set_awb_gain(s, 1);

  Serial.println("# Camera initialized");
  return true;
}

// ================= WIFI =================
void connectToWiFi() {
  WiFi.mode(WIFI_STA);
  WiFi.persistent(false);
  WiFi.setSleep(WIFI_PS_NONE);

  Serial.print("# Connecting to Wi-Fi: ");
  Serial.println(wifi_ssid);

  WiFi.begin(wifi_ssid, wifi_password);

  int attempts = 0;

  while (WiFi.status() != WL_CONNECTED && attempts < 60) {
    delay(500);
    Serial.print("# .\n");
    attempts++;
  }

  if (WiFi.status() == WL_CONNECTED) {
    Serial.println("# Wi-Fi connected");
    Serial.print("# Open browser: http://");
    Serial.println(WiFi.localIP());
    Serial.print("# Capture URL: http://");
    Serial.print(WiFi.localIP());
    Serial.println("/capture");
  } else {
    Serial.println("# Wi-Fi failed. Starting fallback AP mode.");

    WiFi.mode(WIFI_AP);
    WiFi.softAP("ESP32-CAMERA", "12345678");

    Serial.print("# AP IP: http://");
    Serial.println(WiFi.softAPIP());
    Serial.println("# AP SSID: ESP32-CAMERA");
    Serial.println("# AP Password: 12345678");
  }
}

// ================= WEB HANDLERS =================
void handleRoot() {
  server.sendHeader("Cache-Control", "no-store");
  server.send(200, "text/html", index_html);
}

void handleCapture() {
  if (!cameraOK) {
    server.send(500, "text/plain", "Camera not initialized");
    return;
  }

  Serial.println("# Capture request received");

  ledsOn();
  delay(300);

  // Discard one frame to let exposure adjust
  camera_fb_t *fb = esp_camera_fb_get();
  if (fb) {
    esp_camera_fb_return(fb);
  }

  delay(100);

  // Real frame
  fb = esp_camera_fb_get();

  // Turn LEDs off immediately after frame is acquired
  ledsOff();

  if (!fb) {
    Serial.println("# ERROR: Camera capture failed");
    server.send(500, "text/plain", "Camera Capture Failed");
    return;
  }

  server.sendHeader("Cache-Control", "no-store, no-cache, must-revalidate, max-age=0");
  server.sendHeader("Pragma", "no-cache");
  server.sendHeader("Expires", "0");

  server.send_P(
    200,
    "image/jpeg",
    (const char*)fb->buf,
    fb->len
  );

  esp_camera_fb_return(fb);

  Serial.println("# Capture complete, LEDs OFF");
}

// ================= SENSOR READ + CSV =================
void printSensorRow() {
  int16_t adc_NH3 = -999;
  int16_t adc_CH4 = -999;
  int16_t adc_H2S = -999;

  float v_NH3 = -999.0;
  float v_CH4 = -999.0;
  float v_H2S = -999.0;

  float temperature = -999.0;
  float pressure = -999.0;
  float humidity = -999.0;
  float gasRes = -999.0;

  if (adsOK) {
    // PCB mapping:
    // A1 = NH3
    // A2 = CH4
    // A3 = H2S
    adc_NH3 = ads.readADC_SingleEnded(1);
    adc_CH4 = ads.readADC_SingleEnded(2);
    adc_H2S = ads.readADC_SingleEnded(3);

    v_NH3 = ads.computeVolts(adc_NH3);
    v_CH4 = ads.computeVolts(adc_CH4);
    v_H2S = ads.computeVolts(adc_H2S);
  }

  if (bmeOK) {
    bme.startConvert();
    delay(1000);
    bme.update();

    temperature = bme.readTemperature() / 100.0;
    pressure = bme.readPressure();
    humidity = bme.readHumidity() / 1000.0;
    gasRes = bme.readGasResistance();
  }

  // EXACT 10-field numeric CSV:
  // adc_NH3,v_NH3,adc_CH4,v_CH4,adc_H2S,v_H2S,temp_C,pressure_Pa,humidity_pct,bme_gas_ohms

  Serial.print(adc_NH3);
  Serial.print(",");
  Serial.print(v_NH3, 3);
  Serial.print(",");

  Serial.print(adc_CH4);
  Serial.print(",");
  Serial.print(v_CH4, 3);
  Serial.print(",");

  Serial.print(adc_H2S);
  Serial.print(",");
  Serial.print(v_H2S, 3);
  Serial.print(",");

  Serial.print(temperature, 2);
  Serial.print(",");
  Serial.print(pressure, 2);
  Serial.print(",");

  Serial.print(humidity, 2);
  Serial.print(",");
  Serial.println(gasRes, 2);
}

// ================= SETUP =================
void setup() {
  Serial.begin(SERIAL_BAUD);
  delay(2000);

  Serial.println("# Combined sensor + camera firmware start");

  pinMode(LED_PWR_PIN, OUTPUT);
  pinMode(GAS_PWR_PIN, OUTPUT);
  pinMode(BME_PWR_PIN, OUTPUT);

  ledsOff();

  gasOn();
  bmeOn();

  delay(3000);

  Wire.begin(I2C_SDA, I2C_SCL);
  Wire.setClock(I2C_FREQ);

  adsOK = initADS1115();
  bmeOK = initBME688();

  cameraOK = initCamera();

  connectToWiFi();

  server.on("/", handleRoot);
  server.on("/capture", handleCapture);
  server.begin();

  Serial.println("# HTTP server started");

  Serial.print("# ADS1115: ");
  Serial.println(adsOK ? "PASS" : "FAIL");

  Serial.print("# BME688: ");
  Serial.println(bmeOK ? "PASS" : "FAIL");

  Serial.print("# Camera: ");
  Serial.println(cameraOK ? "PASS" : "FAIL");

  Serial.println("# CSV header:");
  Serial.println("adc_NH3,v_NH3,adc_CH4,v_CH4,adc_H2S,v_H2S,temp_C,pressure_Pa,humidity_pct,bme_gas_ohms");

  lastSensorRead = millis();
}

// ================= LOOP =================
void loop() {
  server.handleClient();

  unsigned long now = millis();

  if (now - lastSensorRead >= SENSOR_INTERVAL_MS) {
    lastSensorRead = now;

    gasOn();
    bmeOn();

    printSensorRow();
  }
}

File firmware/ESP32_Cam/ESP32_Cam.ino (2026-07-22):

#include <Wire.h>
#include <Adafruit_ADS1X15.h>
#include <Adafruit_BME680.h>

<<<<<<< HEAD
Adafruit_ADS1115 ads;
Adafruit_BME680 bme;
=======
// ================= YOUR WIFI =================
// ESP32 connects to your normal Wi-Fi.
// Laptop stays on the same Wi-Fi.
const char* wifi_ssid = "Airtel_Sridhar_EXT";
const char* wifi_password = "air12345";

// ================= LED PIN =================
// Your PCB: D0 / GPIO1 controls LED MOSFET, active HIGH
#define LED_PWR_PIN 1
>>>>>>> a62f21f9428228b3dc41fc2a64fe3e862e649a7d

const uint8_t ADS_ADDRESS = 0x48;
const uint8_t BME_ADDRESS = 0x76;

// Change D0 to the actual GPIO number if your board does not define D0
const int CONTROL_PIN = D0;

const unsigned long RETRY_DELAY_MS = 5000;
const unsigned long READ_DELAY_MS = 1000;

bool adsConnected = false;
bool bmeConnected = false;

unsigned long previousReadTime = 0;

<<<<<<< HEAD
// Check whether an I2C address responds
bool isI2CDeviceConnected(uint8_t address) {
  Wire.beginTransmission(address);
  return Wire.endTransmission() == 0;
}

bool connectADS1115() {
  Serial.println("Trying to connect to ADS1115 at 0x48...");

  if (!isI2CDeviceConnected(ADS_ADDRESS)) {
    Serial.println("ADS1115 not found.");
=======
// ================= LED HELPERS =================
void ledsOn() {
  digitalWrite(LED_PWR_PIN, HIGH);
}

void ledsOff() {
  digitalWrite(LED_PWR_PIN, LOW);
}

// ================= HTML =================
const char index_html[] PROGMEM = R"rawliteral(
<!DOCTYPE html>
<html>
<head>
<title>ESP32 Camera</title>
<style>
body{
    font-family:Arial;
    text-align:center;
    background:#f0f0f0;
}
button{
    padding:12px 24px;
    font-size:18px;
    cursor:pointer;
    margin:10px;
}
img{
    margin-top:20px;
    border:2px solid black;
    width:800px;
    max-width:95%;
}
#status{
    margin-top:10px;
    font-weight:bold;
}
</style>
</head>

<body>

<h2>XIAO ESP32-S3 Camera</h2>

<button onclick="capture()">Capture Image</button>

<div id="status">Ready</div>

<br>

<img id="photo">

<script>
async function capture(){
    const status = document.getElementById("status");
    const img = document.getElementById("photo");

    status.innerText = "Capturing...";

    try {
        const response = await fetch("/capture?t=" + Date.now(), {
            cache: "no-store"
        });

        if (!response.ok) {
            status.innerText = "Capture failed: " + response.status;
            return;
        }

        const blob = await response.blob();

        if (img.src) {
            URL.revokeObjectURL(img.src);
        }

        img.src = URL.createObjectURL(blob);
        status.innerText = "Captured at " + new Date().toLocaleTimeString();
    } catch (err) {
        status.innerText = "Error: " + err;
    }
}

window.onload = capture;
</script>

</body>
</html>
)rawliteral";

// ================= ROOT PAGE =================
void handleRoot() {
  server.sendHeader("Cache-Control", "no-store");
  server.send(200, "text/html", index_html);
}

// ================= CAPTURE =================
void handleCapture() {
  Serial.println("Capture request received");

  // Turn LEDs ON only during capture
  ledsOn();

  // Let LEDs and auto-exposure settle
  delay(30);

  // Discard first frame
  camera_fb_t *fb = esp_camera_fb_get();
  if (fb) esp_camera_fb_return(fb);
  delay(100);

  // Discard second frame
  fb = esp_camera_fb_get();
  if (fb) esp_camera_fb_return(fb);
  delay(100);

  // Real capture
  fb = esp_camera_fb_get();

  if (!fb) {
    ledsOff();
    Serial.println("Camera capture failed");
    server.send(500, "text/plain", "Camera Capture Failed");
    return;
  }

  server.sendHeader("Cache-Control", "no-store, no-cache, must-revalidate, max-age=0");
  server.sendHeader("Pragma", "no-cache");
  server.sendHeader("Expires", "0");
  server.setContentLength(fb->len);

  server.send(200, "image/jpeg", "");

  WiFiClient client = server.client();
  client.write(fb->buf, fb->len);

  esp_camera_fb_return(fb);

  ledsOff();

  Serial.println("Capture complete, LEDs OFF");
}

// ================= CAMERA INIT =================
bool initCamera() {
  camera_config_t config;

  config.ledc_channel = LEDC_CHANNEL_0;
  config.ledc_timer   = LEDC_TIMER_0;

  config.pin_d0 = Y2_GPIO_NUM;
  config.pin_d1 = Y3_GPIO_NUM;
  config.pin_d2 = Y4_GPIO_NUM;
  config.pin_d3 = Y5_GPIO_NUM;
  config.pin_d4 = Y6_GPIO_NUM;
  config.pin_d5 = Y7_GPIO_NUM;
  config.pin_d6 = Y8_GPIO_NUM;
  config.pin_d7 = Y9_GPIO_NUM;

  config.pin_xclk = XCLK_GPIO_NUM;
  config.pin_pclk = PCLK_GPIO_NUM;
  config.pin_vsync = VSYNC_GPIO_NUM;
  config.pin_href = HREF_GPIO_NUM;

  config.pin_sccb_sda = SIOD_GPIO_NUM;
  config.pin_sccb_scl = SIOC_GPIO_NUM;

  config.pin_pwdn = PWDN_GPIO_NUM;
  config.pin_reset = RESET_GPIO_NUM;

  config.xclk_freq_hz = 20000000;
  config.pixel_format = PIXFORMAT_JPEG;

  // Good starting quality for ML images
  config.frame_size = FRAMESIZE_SVGA;   // 800x600
  config.jpeg_quality = 8;              // lower number = better quality

  config.fb_count = 1;
  config.fb_location = CAMERA_FB_IN_PSRAM;
  config.grab_mode = CAMERA_GRAB_LATEST;

  esp_err_t err = esp_camera_init(&config);

  if (err != ESP_OK) {
    Serial.printf("Camera init failed: 0x%x\n", err);
>>>>>>> a62f21f9428228b3dc41fc2a64fe3e862e649a7d
    return false;
  }

  if (!ads.begin(ADS_ADDRESS, &Wire)) {
    Serial.println("ADS1115 initialization failed.");
    return false;
  }

<<<<<<< HEAD
  ads.setGain(GAIN_ONE);
=======
  s->set_brightness(s, -1);
  s->set_contrast(s, 1);
  s->set_saturation(s, 0);

  s->set_gain_ctrl(s, 1);
  s->set_exposure_ctrl(s, 1);
  s->set_whitebal(s, 1);
  s->set_awb_gain(s, 1);
>>>>>>> a62f21f9428228b3dc41fc2a64fe3e862e649a7d

  Serial.println("ADS1115 connected.");
  return true;
}

<<<<<<< HEAD
bool connectBME680() {
  Serial.println("Trying to connect to BME680 at 0x76...");

  if (!isI2CDeviceConnected(BME_ADDRESS)) {
    Serial.println("BME680 not found.");
    return false;
  }

  if (!bme.begin(BME_ADDRESS, &Wire)) {
    Serial.println("BME680 initialization failed.");
    return false;
  }

  bme.setTemperatureOversampling(BME680_OS_8X);
  bme.setHumidityOversampling(BME680_OS_2X);
  bme.setPressureOversampling(BME680_OS_4X);
  bme.setIIRFilterSize(BME680_FILTER_SIZE_3);

  // Gas heater: 320°C for 150 ms
  bme.setGasHeater(320, 150);

  Serial.println("BME680 connected.");
  return true;
}
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

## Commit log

2025-08-04 Rename SpoilFree Fridge BB prototype_bb.jpg to Fritzing prototype design.jpg
2026-03-21 Add files via upload
    CSV data files for first sample of cooked rice
    [sensor_log_20260318_153343.csv, sensor_log_20260319_230346.csv, sensor_log_20260319_230421.csv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]
2026-05-28 Started PCB Design
    [FoodSpoilDetection.kicad_pcb, FoodSpoilDetection.kicad_sch]
2026-05-28 name change for PCB file
    [FoodSpoilDetection.kicad_pcb, FoodSpoilDetection.kicad_sch]
2026-05-28 pcb edits
    [FoodSpoilDetection.kicad_pcb, FoodSpoilDetection.kicad_sch]
2026-05-28 added 492 schematics
    [Power_Schematic_Project_06.kicad_sch, Processor_Schematic_Project_06.kicad_sch, Sensor_Functions_Project_06.kicad_sch]
2026-05-28 changes pcb
2026-05-28 added bss138 footprints
2026-05-28 changes to PCB -- Added LEDs and rearranged Layout
    [FoodSpoilDetection.kicad_pcb, FoodSpoilDetection.kicad_sch]
2026-05-29 pcb changes
    [FoodSpoilDetection.kicad_pcb, FoodSpoilDetection.kicad_sch]
2026-05-29 updated schematic (almost finalized)
    [FoodSpoilDetection.kicad_pcb, FoodSpoilDetection.kicad_sch, SEN0570-DIP.PcbLib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]
2026-05-29 finished traces for V1 PCB
2026-05-30 added mounting holes
    Need to align mounting holes and fiduciaries
    [FoodSpoilDetection.kicad_pcb, FoodSpoilDetection.kicad_sch]
2026-05-31 restructured github
    [sensor_log_20260318_153343.csv, sensor_log_20260319_230346.csv, sensor_log_20260319_230421.csv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]
2026-05-31 Revise README to reflect project updates and enhancements
    Updated project description to include IoT capabilities, ESP32-S3 Sense, and image classification features. Revised sections on data transmission, power source, and prototype development.
2026-06-01 traces to mounting holes and edits to rounting
    [FoodSpoilDetection.kicad_pcb, FoodSpoilDetection.kicad_sch]
2026-06-08 Changes to PCB
    [FoodSpoilDetection.kicad_pcb]
2026-06-09 switch update
    [FoodSpoilDetection.kicad_pcb, FoodSpoilDetection.kicad_sch]
2026-06-10 so close
    [FoodSpoilDetection.kicad_pcb, FoodSpoilDetection.kicad_sch, Power_Schematic_Project_06.kicad_sch]
2026-06-10 finished routing
    [FoodSpoilDetection.kicad_pcb]
2026-06-24 added esp32 cam code for click to take photo on server
    [FoodSpoilDetection-B_Cu.gbr, FoodSpoilDetection-B_Mask.gbr, FoodSpoilDetection-B_Paste.gbr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]
2026-06-25 firmware for pcb
2026-06-26 pcb works
    [FoodSpoilDetection.kicad_pcb]
2026-06-28 added code for cam capture with python
    [FoodSpoilDetection.kicad_pcb]
2026-07-16 Model implementations
    [observations_template.csv]
2026-07-18 updated unsupervised models
    [observations_template.csv]
2026-07-22 control runs
    [image_log.csv, observations_template.csv, sensor_log.csv]
2026-07-24 camera implementation
    [image_log.csv, sensor_log.csv]
2026-07-28 esp configuration completed
    [image_log.csv, sensor_log.csv]
2026-07-29 pilot chicken run done
    [image_log.csv, sensor_log.csv]
2026-08-02 2nd run
    [image_log.csv, sensor_log.csv]
2026-08-05 run 3 completed
    [camera_features.csv, camera_reliability_by_hour.csv, confirmation_comparison_curves.csv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]
2026-08-10 non optimized power test
    [camera_features.csv, camera_reliability_by_hour.csv, candidate_session_results.csv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]
2026-08-21 completed power savings with wi-fi
    [image_log.csv, sensor_log.csv]
